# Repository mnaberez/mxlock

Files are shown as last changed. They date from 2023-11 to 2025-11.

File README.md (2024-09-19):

# MXLock

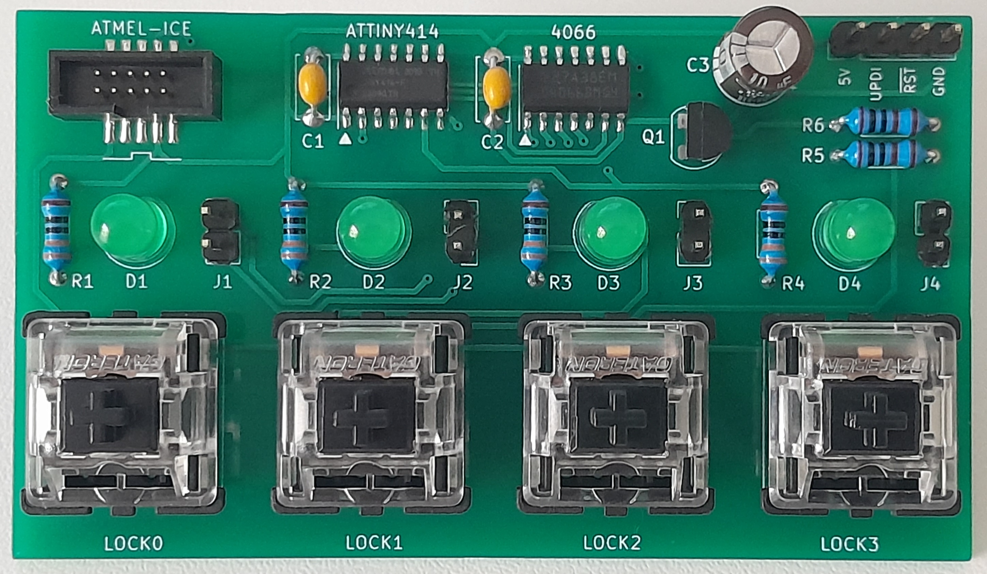
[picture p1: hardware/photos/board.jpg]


MXLock is a two-chip circuit that allows up to four mechanically locking keys (push-on, push-off) to be simulated using regular momentary key switches.

Many older computer keyboards have mechanically locking keys.  For example, the Commodore 128 has three locking keys: `SHIFT LOCK`, `CAPS LOCK`, and `40/80`.  The MXLock circuit can be included on the PCB of replacement keyboard projects, such as those using Cherry MX keys, so that the entire keyboard can be made from momentary key switches.

Features:

 - Simulates up to 4 locking keys using an [ATtiny214/414/814](https://web.archive.org/web/20231029180615if_/https://ww1.microchip.com/downloads/en/DeviceDoc/40001912A.pdf) and a [4066](https://web.archive.org/web/20231029180910if_/https://www.ti.com/lit/ds/symlink/cd4066b-mil.pdf)
 - Shows the on/off state of each key with LEDs
 - Remembers the lock states between power cycles (useful for mode keys like `40/80`)
 - Resets the computer by pulling `/RESET` low if the `LOCK0` key is held down
 - Puts the ATtiny to sleep between keypresses to save power

## Hardware

The [`hardware/`](./hardware/) directory in this repository contains the schematic and a PCB layout for the demonstration board pictured above.  It can be used to test the MXLock circuit.

The circuit is intended to be integrated directly onto the PCB of a keyboard.  Steve Gray's [C128SX keyboard](http://6502.org/users/sjgray/projects/mxkeyboards/) is an example of a keyboard using the circuit.

## Firmware

The firmware is written in AVR assembly language.  It can be assembled and flashed using open source software and inexpensive hardware.  See [`firmware/`](./firmware/) for the source code and instructions.

## Author

[Mike Naberezny](https://github.com/mnaberez)

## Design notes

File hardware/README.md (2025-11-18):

# Hardware 

The MXLock circuit consists of two main components: an ATtiny214/414/814 microcontroller and a 4066 quad analog switch.  The momentary key switches are connected directly to the microcontroller.  The 4066 is connected to the computer's keyboard matrix.

Up to four locking keys can be simulated, `LOCK0` through `LOCK3`: 

 - `LOCK0` can also reset the computer if held down.  If the circuit on the demo board is used, the computer must have an active-low reset input (`/RESET`) like on the 6502.
 - `LOCK1` and `LOCK2` have no special characteristics.
 - `LOCK3` has the limitation that its LED that can't be turned off programmatically unless its 4066 contact is also turned off.  LOCK3 may also prevent the ATtiny from entering shutdown mode (see note below).   If fewer than four keys are required, choose the others instead.

The design files are in KiCad format.  A [PDF schematic](./schematic.pdf) and [Gerber files](./gerbers.zip) are also available.  The PCB is only for demonstration and testing purposes; the MXLock circuit is intended to be integrated onto a keyboard.

See [`firmware/`](../firmware) for how to program the microcontroller.

## Power Consumption

The ATtiny is put into full shutdown mode (CPU and internal oscillator stopped) between keypressess.  At 5.0 VDC, with no key being pressed down and the 4066 contacts all in the open state, the [Joulescope JS220](https://www.joulescope.com) measures the demo board as drawing about 140 nA / 0.140 μA.

The demo board consumes about 8.5 mA total when one of the contacts is closed and its LED is lit.  This power draw is dominated by the LED.  The board consumes about 8.5 * 4 = 34 mA when all four contacts are closed and their LEDs are lit.  Different LEDs and current limiting resistors can be used to reduce power.  The LEDs can also be omitted for the lowest possible current draw.

`LOCK3` should be avoided if power consumption is a concern as it may prevent the ATtiny from shutting down.  Pressing `LOCK3` a few times may put the ATtiny into a state where it draws about 1.5 mA between keypresses even though all contacts and LEDs are off.  In this state, pressing `LOCK3` a few more times may return the current draw to normal (~ 140 nA).  The input pin for `LOCK3` is shared with the UPDI interface.  Presumably, activity on this pin puts the chip's internal UPDI circuitry into a state where it draws more power.

Notes:

- If a UPDI programmer is connected, the power consumption of the demo board increases.  Disconnect UPDI before measuring current.

- If different LEDs or current limiting resistors are used, each LED must draw no more than 12 mA or else damage to the ATtiny may occur.

## EEPROM Life

The internal EEPROM of the ATtiny is used to restore the state of the keys after power is lost.  The EEPROM is updated whenever a key changes state.  The firmware uses a wear-leveling algorithm to spread writes across the EEPROM locations for maximum life.

Although the ATtiny214 is supported, it should be avoided if longevity is a concern:

The ATtiny414 and ATtiny814 are preferred because they have twice the EEPROM space (128 bytes) as the ATtiny214 (64 bytes).  The ATtiny214 should withstand 6.4 million key
changes, the ATtiny414 and ATtiny814 should withstand twice that at 12.8 million.  

## Parts List

The demo board uses the following components:

| Part | Qty | Reference Designators |
|---|-----|---|
| [0.1uF 50V Capacitor](https://www.mouser.com/ProductDetail/594-K104M15X7RF53L2) | 2 | C1, C2 |
| [10uF 100V Capacitor](https://www.mouser.com/ProductDetail/661-E-101L100MF11D) | 1 | C3 |
| [T1-3/4 Green LED](https://www.mouser.com/ProductDetail/606-4304H5) | 4 | D1, D2, D3, D4 |
| [1x2 2.54mm Male Header](https://www.mouser.com/ProductDetail/649-1012937890201BLF) | 4 | J1, J2, J3, J4 |
| [10-pin 2x5 1.27mm Male Shrouded Header SMT](https://www.ebay.com/itm/171560426679) | 1 | J6 |
| [1x4 2.54mm Male Header](https://www.mouser.com/ProductDetail/649-1012937890401BLF) | 1 | J5 |
| [2N3904 Transistor](https://www.mouser.com/ProductDetail/512-2N3904BU) | 1 | Q1 |
| [330 ohm 1/4W Resistor](https://www.mouser.com/ProductDetail/603-MFR-25FTE52-330R) | 3 | R1, R2, R3, R4 |
| [1K 1/4W Resistor](https://www.mouser.com/ProductDetail/603-MFR-25FTF52-1K) | 1 | R5, R6 |
| [MX-Compatible Keyboard Switch](https://www.amazon.com/dp/B07K7J38SB) | 4 | SW1, SW2, SW3, SW4 |
| [ATtiny414-SSN](https://www.mouser.com/ProductDetail/579-ATTINY414-SSN) | 1 | U1 |
| [CD4066BM](https://www.mouser.com/ProductDetail/595-CD4066BM96) | 1 | U2 |

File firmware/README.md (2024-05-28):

# Firmware

The firmware is written in AVR assembly language.  It can be built for the ATtiny214, ATtiny414, and ATtiny814.

## Build

Building requires:

- ASAVR (part of the [ASxxxx](https://shop-pdp.net/ashtml/) cross-assemblers package)
- GNU [Make](https://www.gnu.org/software/make/)
- A Unix-like operating system (e.g. Linux, macOS)

Run `make` to produce Intel Hex files for the flash, fuses, and EEPROM:

    make MCU=t414

If `MCU=` is not given, the default target is `t414` (ATtiny414).  Valid targets are `MCU=t214`, `MCU=t414`, and `MCU=t814`.  It may be helpful to read the [`Makefile`](./Makefile) and the [GitHub workflow](../.github/workflows/main.yml).

## Flash

MXLock has a dedicated header for connecting to an [Atmel-ICE](https://www.microchip.com/en-us/development-tool/ATATMEL-ICE).  It also has pins on its 2.54mm header that can be used to connect to a different UPDI programmer.  In both cases, [AVRDUDE 7.2 or later](https://github.com/avrdudes/avrdude) is used.

### Atmel-ICE

Connect the Atmel-ICE to the dedicated header on the MXLock board.  Also connect a 5VDC power supply to the 5V and GND pins on the 2.54mm header.  Install the Atmel-ICE drivers and then run `make program`, specifying `MCU=` if needed.

### SerialUPDI

A SerialUPDI programmer can also be used.  One can be made from an FTDI [TTL-232R-5V](https://www.mouser.com/ProductDetail/895-TTL-232R-5V) cable and a 1KΩ resistor.  Make the following connections to the MXLock board:

- FTDI RX → UPDI
- FTDI TX → 1KΩ resistor → UPDI
- FTDI GND → GND

A 5VDC power supply must also be connected to the MXLock board.  The 5V pin on the FTDI cable may be used as the power supply.

Since macOS and most Linux distributions ship with built-in FTDI drivers, drivers are not normally required.  Run `make program` and use `ISPFLAGS=` to set the SerialUPDI options for AVRDUDE:

    make program MCU=t414 ISPFLAGS='-c serialupdi -P /dev/cu.usbserial-FTABCDEF'

The above command will flash an ATTiny414 using SerialUPDI on port `/dev/cu.usbserial-FTABCDEF`.

## References

- [ATtiny214/414/814 Datasheet](https://web.archive.org/web/20231029180615if_/https://ww1.microchip.com/downloads/en/DeviceDoc/40001912A.pdf)

- [AVR Instruction Set Manual](https://web.archive.org/web/20211122051203if_/http://ww1.microchip.com/downloads/en/devicedoc/atmel-0856-avr-instruction-set-manual.pdf)

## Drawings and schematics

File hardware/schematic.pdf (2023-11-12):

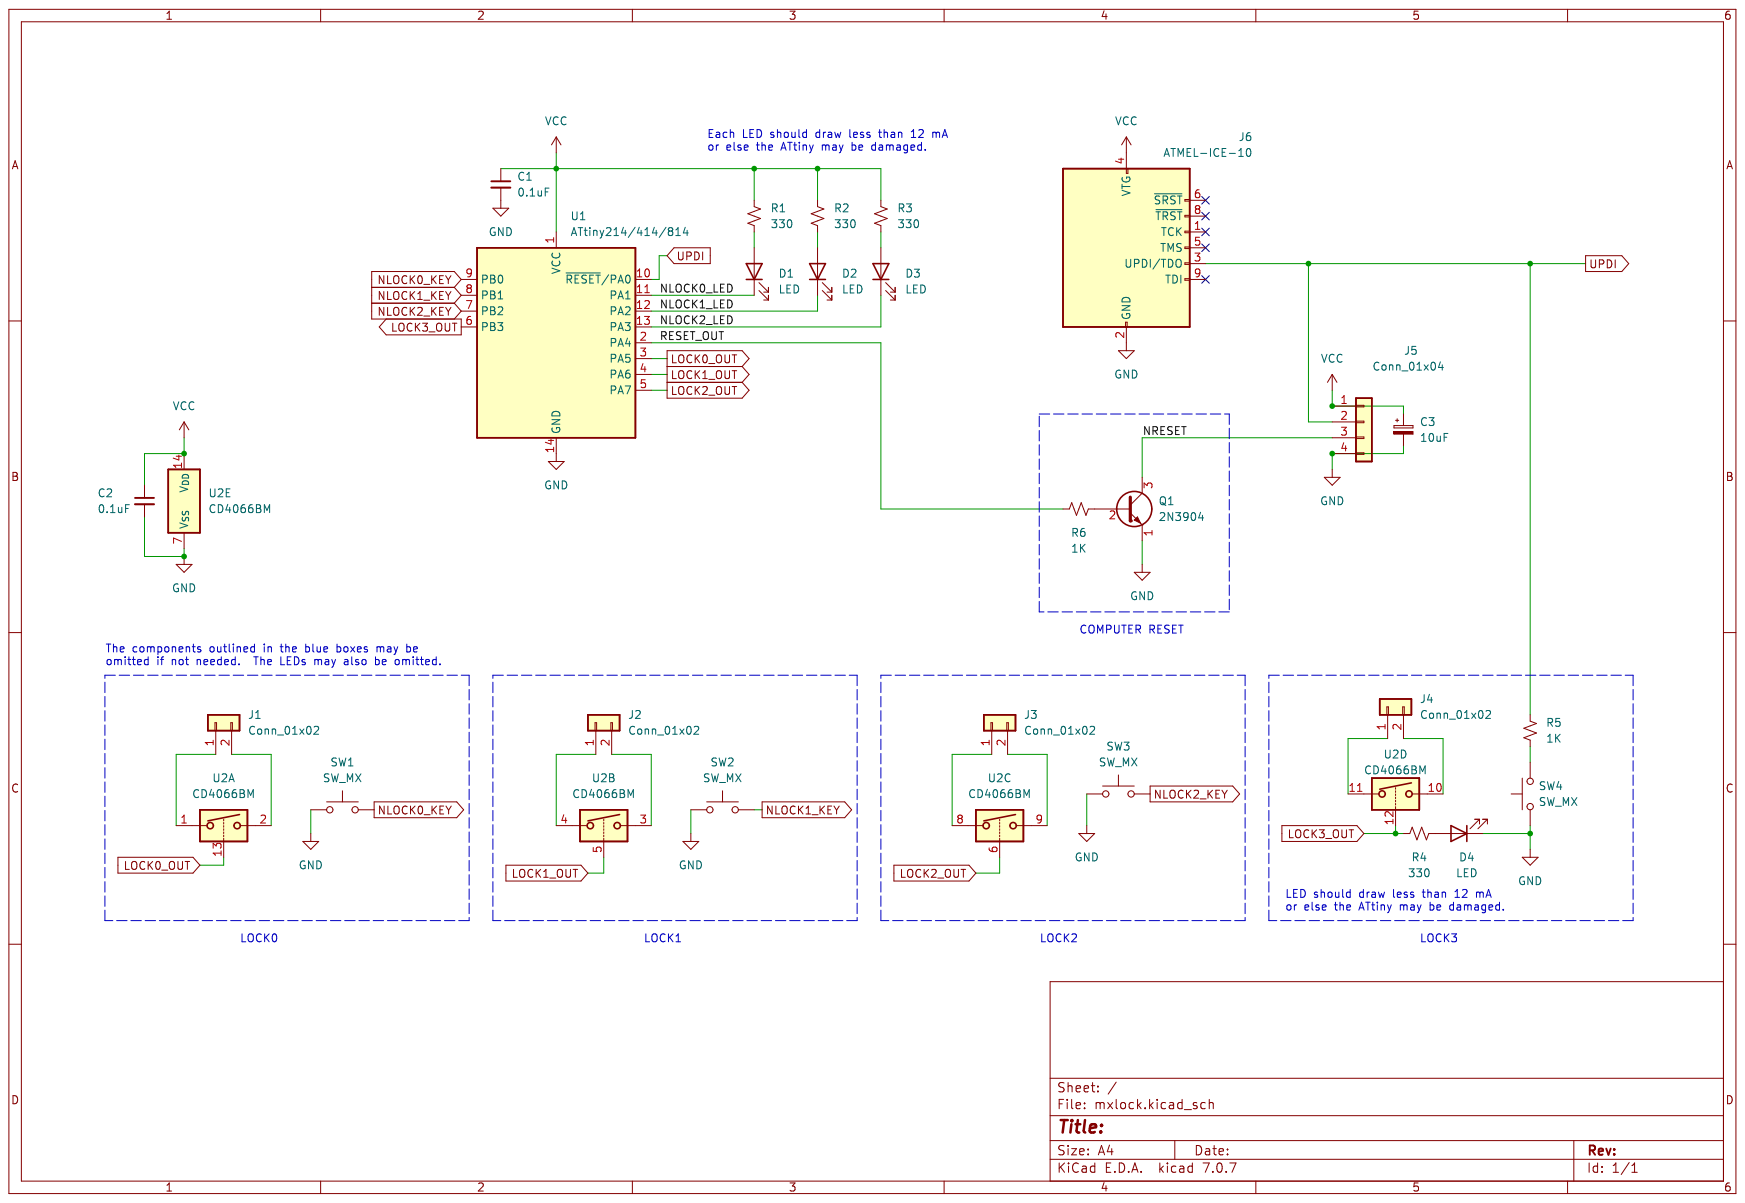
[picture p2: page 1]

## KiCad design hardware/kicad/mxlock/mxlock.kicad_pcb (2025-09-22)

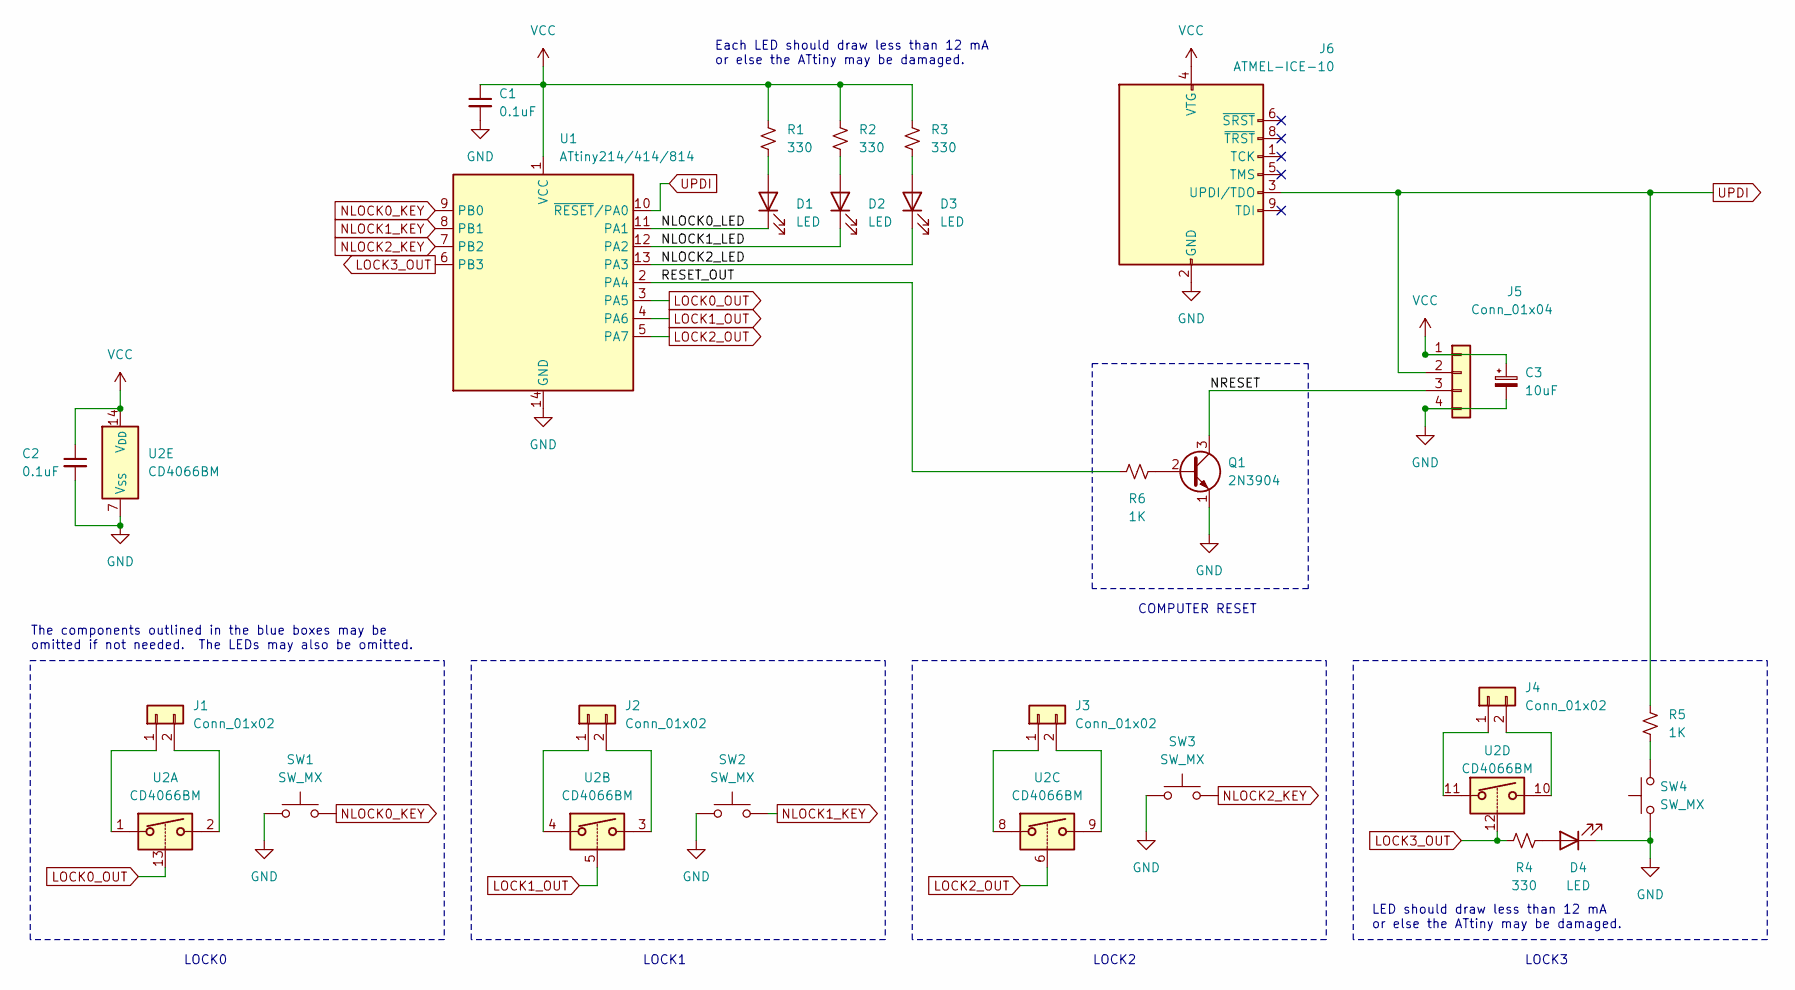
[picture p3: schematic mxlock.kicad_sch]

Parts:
C1, C2: 0.1uF; C_Disc_D5.0mm_W2.5mm_P5.00mm
C3: 10uF; CP_Radial_D6.3mm_P2.50mm
D1, D2, D3, D4: LED; LED_D5.0mm
J1, J2, J3, J4: Conn_01x02; PinHeader_1x02_P2.54mm_Vertical
J5: Conn_01x04; PinHeader_1x04_P2.54mm_Vertical
J6: ATMEL-ICE-10; PinHeader_2x05_P1.27mm_Shrouded_Vertical_SMD_Handsolder
Q1: 2N3904; TO-92_HandSolder
R1, R2, R3, R4: 330; R_Axial_DIN0204_L3.6mm_D1.6mm_P7.62mm_Horizontal
R5, R6: 1K; R_Axial_DIN0204_L3.6mm_D1.6mm_P7.62mm_Horizontal
SW1, SW2, SW3, SW4: SW_MX; SW_Cherry_MX_1.00u_PCB
U1: ATtiny214/414/814; SOIC-14_3.9x8.7mm_P1.27mm
U2: CD4066BM; SO-14_3.9x8.65mm_P1.27mm

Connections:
/NLOCK0_LED: D1.1 (K), U1.11 (PA1)
/NLOCK1_LED: D2.1 (K), U1.12 (PA2)
/NLOCK2_LED: D3.1 (K), U1.13 (PA3)
/NRESET: J5.3, Q1.3 (C)
/RESET_OUT: R6.1, U1.2 (PA4)
GND: C1.2, C2.2, C3.2, D4.1 (K), J5.4, J6.2 (GND), J6.10 (GND), Q1.1 (E), SW1.1, SW2.1, SW3.1, SW4.1, U1.14 (GND), U2.7 (V_{SS})
LOCK0_OUT: U1.3 (PA5), U2.13
LOCK1_OUT: U1.4 (PA6), U2.5
LOCK2_OUT: U1.5 (PA7), U2.6
LOCK3_OUT: R4.1, U1.6 (PB3), U2.12
NLOCK0_KEY: SW1.2, U1.9 (PB0)
NLOCK1_KEY: SW2.2, U1.8 (PB1)
NLOCK2_KEY: SW3.2, U1.7 (PB2)
unnamed: D1.2 (A), R1.2
unnamed: D2.2 (A), R2.2
unnamed: D3.2 (A), R3.2
unnamed: D4.2 (A), R4.2
unnamed: J1.1, U2.1
unnamed: J1.2, U2.2
unnamed: J2.1, U2.4
unnamed: J2.2, U2.3
unnamed: J3.1, U2.8
unnamed: J3.2, U2.9
unnamed: J4.1, U2.11
unnamed: J4.2, U2.10
unnamed: Q1.2 (B), R6.2
unnamed: R5.1, SW4.2
UPDI: J5.2, J6.3 (UPDI/TDO), R5.2, U1.10 (~RESET/PA0)
VCC: C1.1, C2.1, C3.1, J5.1, J6.4 (VTG), R1.1, R2.1, R3.1, U1.1 (VCC), U2.14 (V_{DD})

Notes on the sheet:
LOCK0
Each LED should draw less than 12 mA or else the ATtiny may be damaged.
LOCK3
LOCK1
COMPUTER RESET
The components outlined in the blue boxes may be omitted if not needed. The LEDs may also be omitted.
LED should draw less than 12 mA or else the ATtiny may be damaged.
LOCK2

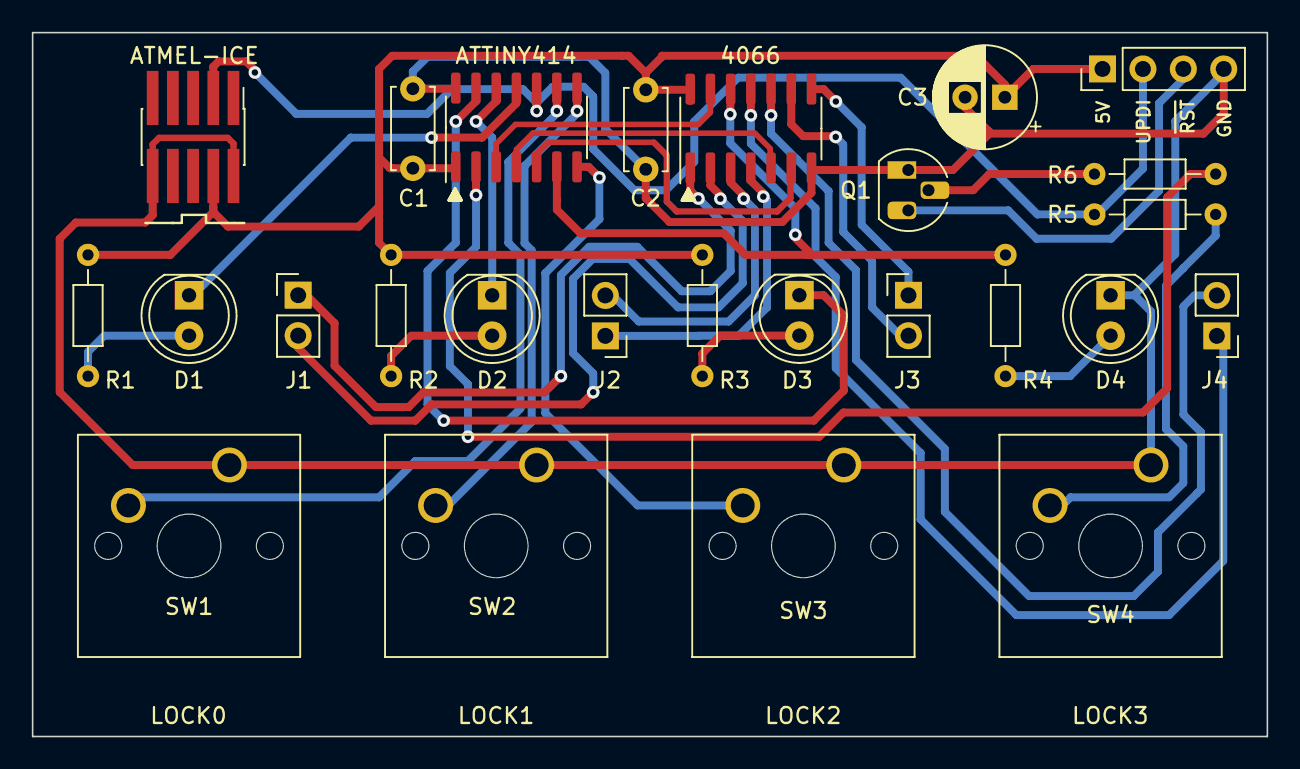
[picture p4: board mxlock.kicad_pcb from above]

Board: 2 copper layers, 77.6 x 44.2 mm, 26 parts (0 on the bottom side), 29 nets.

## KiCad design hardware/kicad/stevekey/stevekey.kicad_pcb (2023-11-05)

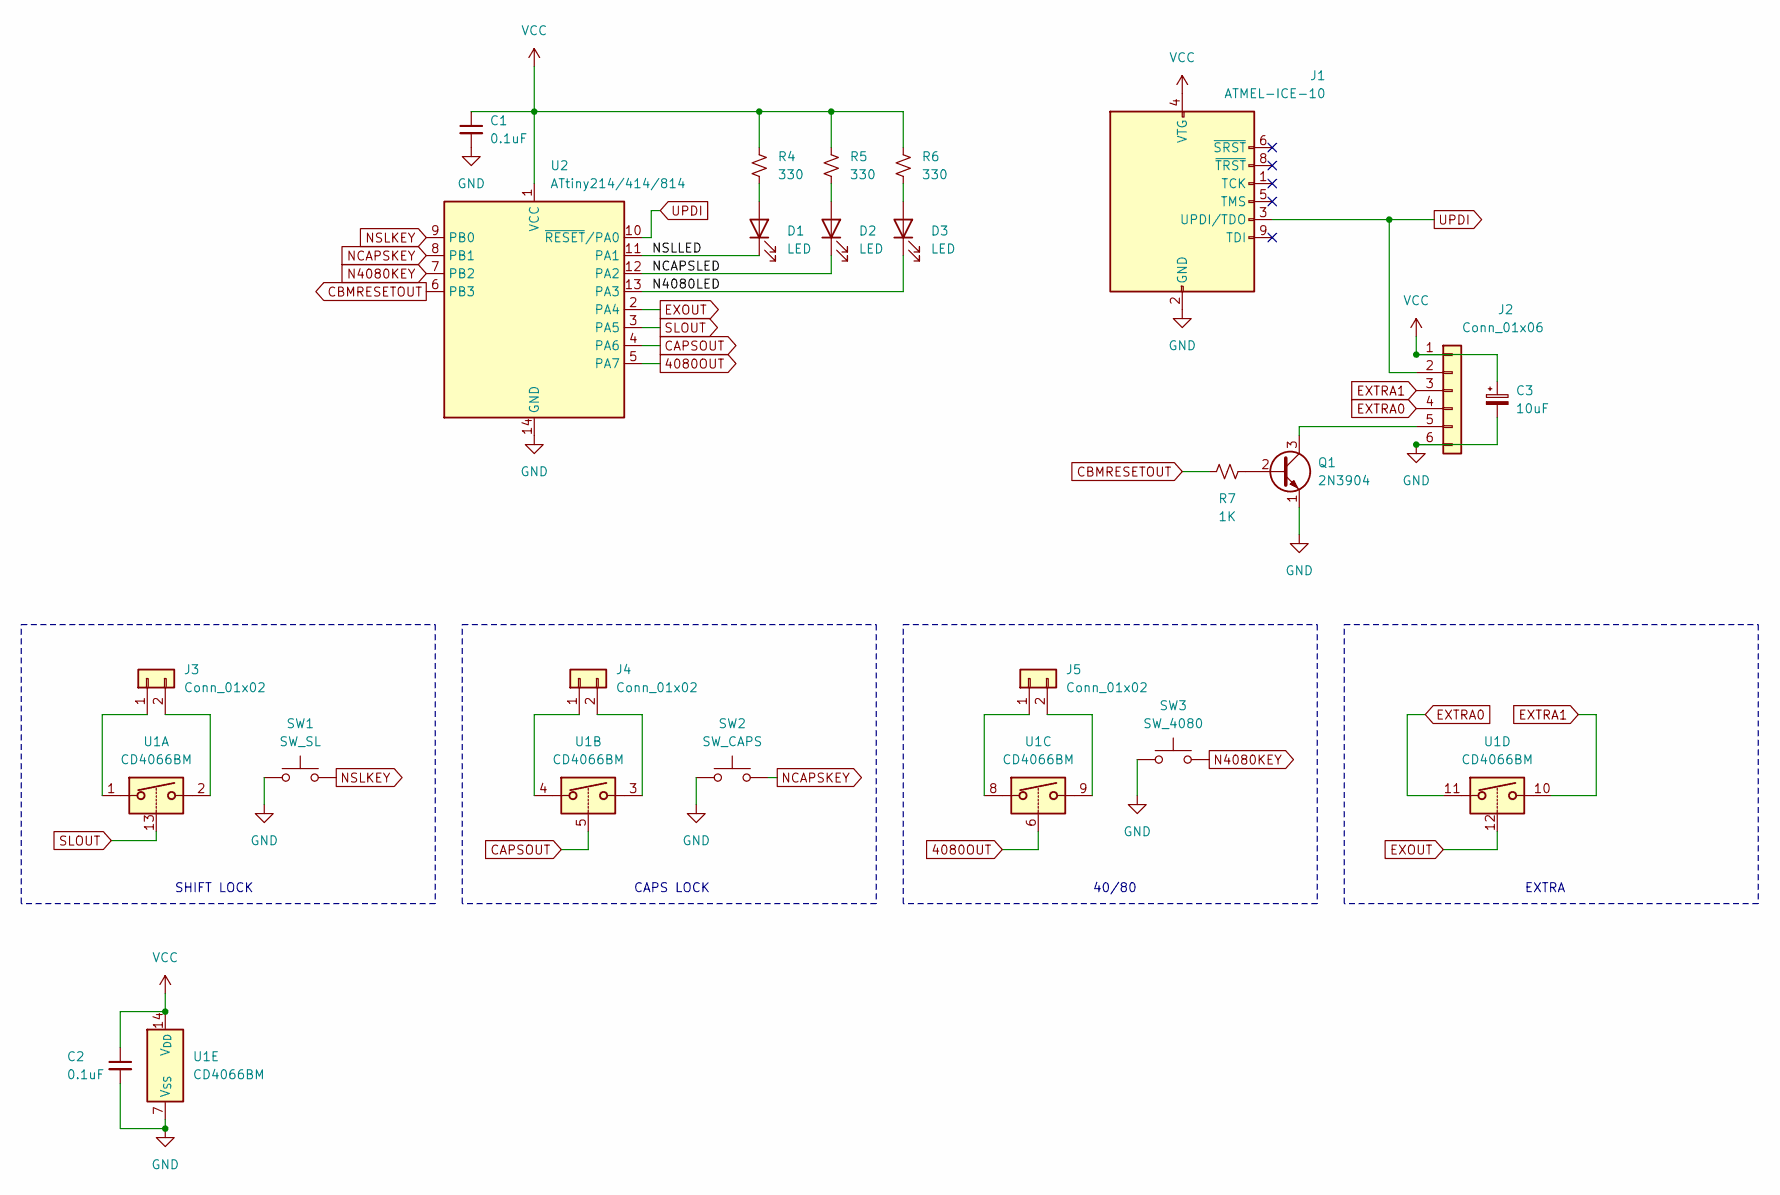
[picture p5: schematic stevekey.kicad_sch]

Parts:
C1, C2: 0.1uF; C_Disc_D5.0mm_W2.5mm_P5.00mm
C3: 10uF; CP_Radial_D6.3mm_P2.50mm
D1, D2, D3: LED; LED_D5.0mm
J1: ATMEL-ICE-10; PinHeader_2x05_P1.27mm_Shrouded_Vertical_SMD_Handsolder
J2: Conn_01x06; PinHeader_1x06_P2.54mm_Vertical
J3, J4, J5: Conn_01x02; PinHeader_1x02_P2.54mm_Vertical
Q1: 2N3904; TO-92_Inline
R4, R5, R6: 330; R_Axial_DIN0204_L3.6mm_D1.6mm_P7.62mm_Horizontal
R7: 1K; R_Axial_DIN0204_L3.6mm_D1.6mm_P7.62mm_Horizontal
SW1: SW_SL; SW_Cherry_MX_1.00u_PCB
SW2: SW_CAPS; SW_Cherry_MX_1.00u_PCB
SW3: SW_4080; SW_Cherry_MX_1.00u_PCB
U1: CD4066BM; SO-14_3.9x8.65mm_P1.27mm
U2: ATtiny214/414/814; SOIC-14_3.9x8.7mm_P1.27mm

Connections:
4080OUT: U1.6, U2.5 (PA7)
/N4080LED: D3.1 (K), U2.13 (PA3)
/NCAPSLED: D2.1 (K), U2.12 (PA2)
/NSLLED: D1.1 (K), U2.11 (PA1)
CAPSOUT: U1.5, U2.4 (PA6)
CBMRESETOUT: R7.1, U2.6 (PB3)
EXOUT: U1.12, U2.2 (PA4)
EXTRA0: J2.4, U1.11
EXTRA1: J2.3, U1.10
GND: C1.2, C2.2, C3.2, J1.2 (GND), J1.10 (GND), J2.6, Q1.1 (E), SW1.1, SW2.1, SW3.1, U1.7 (V_{SS}), U2.14 (GND)
N4080KEY: SW3.2, U2.7 (PB2)
NCAPSKEY: SW2.2, U2.8 (PB1)
NSLKEY: SW1.2, U2.9 (PB0)
unnamed: D1.2 (A), R4.2
unnamed: D2.2 (A), R5.2
unnamed: D3.2 (A), R6.2
unnamed: J2.5, Q1.3 (C)
unnamed: J3.1, U1.1
unnamed: J3.2, U1.2
unnamed: J4.1, U1.4
unnamed: J4.2, U1.3
unnamed: J5.1, U1.8
unnamed: J5.2, U1.9
unnamed: Q1.2 (B), R7.2
SLOUT: U1.13, U2.3 (PA5)
UPDI: J1.3 (UPDI/TDO), J2.2, U2.10 (~RESET/PA0)
VCC: C1.1, C2.1, C3.1, J1.4 (VTG), J2.1, R4.1, R5.1, R6.1, U1.14 (V_{DD}), U2.1 (VCC)

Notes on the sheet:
SHIFT LOCK
EXTRA
CAPS LOCK
40/80

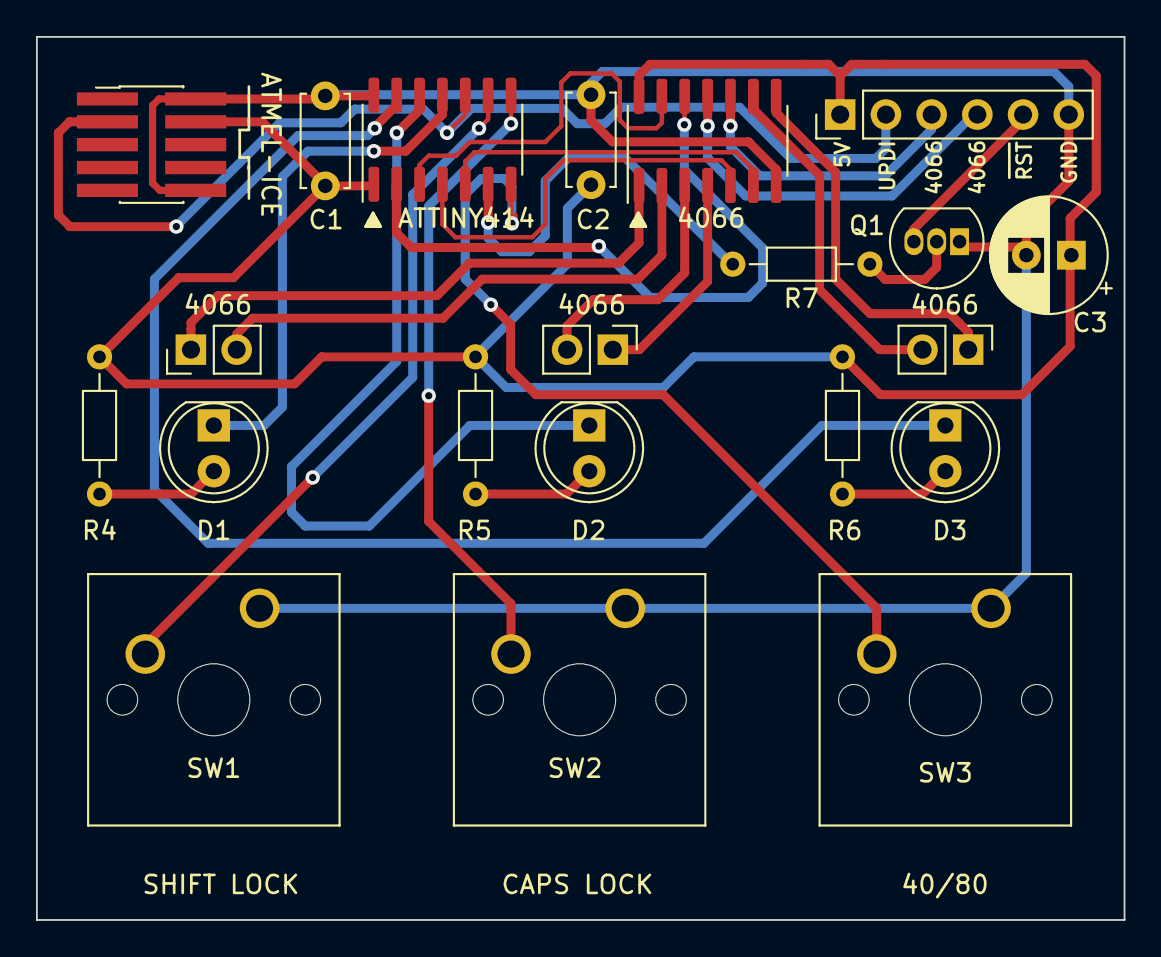
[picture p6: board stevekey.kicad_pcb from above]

Board: 2 copper layers, 60.4 x 49.1 mm, 21 parts (0 on the bottom side), 27 nets.

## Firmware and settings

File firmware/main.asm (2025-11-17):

;ATtiny214/ATtiny414/ATtiny814
;1  VCC
;2  PA4 out RESET_OUT (0=/RESET=open, 1=/RESET=low)
;3  PA5 out LOCK0_OUT to 4066 (0=off, 1=on)
;4  PA6 out LOCK1_OUT to 4066 (0=off, 1=on)
;5  PA7 out LOCK2_OUT to 4066 (0=off, 1=on)
;6  PB3 out LOCK3_OUT to 4066 and LED (0=off, 1=on)
;7  PB2 in /LOCK2_KEY (0=down, 1=up)
;8  PB1 in /LOCK1_KEY (0=down, 1=up)
;9  PB0 in /LOCK0_KEY (0=down, 1=up)
;10 UPDI/PA0 in /LOCK3_KEY (0=down, 1=up)
;11 PA1 out /LOCK0_LED (0=on, 1=off)
;12 PA2 out /LOCK1_LED (0=on, 1=off)
;13 PA3 out /LOCK2_LED (0=on, 1=off)
;14 GND

    ;Definitions file will be included first by the Makefile.

    .area code (abs)
    .list (me)
    .32bit

;RAM
current_keys     = SRAM_START+0 ;Current state of keys
previous_keys    = SRAM_START+1 ;State of keys last time around the main loop
lock0_down_ticks = SRAM_START+2 ;Number of ticks LOCK0 has been held down

;Constants
TICK_MS         = 20    ;Milliseconds in one tick
RESET_MS        = 50    ;Milliseconds to hold /RESET low to reset
LOCK0_DOWN_MS   = 1500  ;Milliseconds of LOCK0 held down to cause reset

;Constants for bit positions used with GPIO functions
LOCK3 = 3
LOCK2 = 2
LOCK1 = 1
LOCK0 = 0

    .org PROGMEM_START/2  ;/2 because PROGMEM_START constant is byte-addressed
                          ;but ASAVR treats program space as word-addressed.

    ;Vectors
    rjmp reset            ;00 RESET
    rjmp isr_fatal        ;01 CRCSCAN_NMI
    rjmp isr_fatal        ;02 BOD_VLM
    rjmp isr_pin_change   ;03 PORTA_PORT
    rjmp isr_pin_change   ;04 PORTB_PORT
    rjmp isr_fatal        ;05 Undefined
    rjmp isr_fatal        ;06 RTC_CNT
    rjmp isr_fatal        ;07 RTC_PIT
    rjmp isr_fatal        ;08 TCA0_LUNF / TCA0_OVF
    rjmp isr_fatal        ;09 TCA0_HUNF
    rjmp isr_fatal        ;0a TCA0_LCMP0 / TCA0_CMP0
    rjmp isr_fatal        ;0b TCA0_LCMP1 / TCA0_CMP1
    rjmp isr_fatal        ;0c TCA0_CMP2 / TCA0_LCMP2
    rjmp isr_fatal        ;0d TCB0_INT
    rjmp isr_fatal        ;0e TCD0_OVF
    rjmp isr_fatal        ;0f TCD0_TRIG
    rjmp isr_fatal        ;10 AC0_AC
    rjmp isr_fatal        ;11 ACD0_RESRDY
    rjmp isr_fatal        ;12 ACD0_WCOMP
    rjmp isr_fatal        ;13 TWI0_TWIS
    rjmp isr_fatal        ;14 TWI0_TWIM
    rjmp isr_fatal        ;15 SPI0_INT
    rjmp isr_fatal        ;16 USART0_RXC
    rjmp isr_fatal        ;17 USART0_DRE
    rjmp isr_fatal        ;18 USART0_TXC
    rjmp isr_fatal        ;19 NVMCTRL_EE

    ;Code starts at first location after vectors
    .assume . - ((PROGMEM_START/2) + INT_VECTORS_SIZE)

;Unexpected interrupt
;
isr_fatal:
    jmp fatal

;Pin change interrupt
;
;The pin change interrupts are enabled in order to wake
;from sleep but are not used for anything else.  When a
;pin change interrupt occurs, its flags must be cleared.
;
isr_pin_change:
    push r16
    ldi r16, 0xff                       ;Clear every flag
    sts PORTA_INTFLAGS, r16             ;  on PORTA
    sts PORTB_INTFLAGS, r16             ;  on PORTB
    pop r16
    reti

;Reset
;
;Perform all startup activities, then start running the main loop.
;
reset:
    ;Set main clock to 16 MHz to get through init quickly
    ;in case the computer checks for a key at boot.
    ldi r16, CPU_CCP_IOREG_gc
    clr r17                             ;No prescaler = 16 MHz
    out CPU_CCP, r16                    ;Unlock Protected I/O Registers
    sts CLKCTRL_MCLKCTRLB, r17          ;Disable main clock prescaler

    ;Initialize stack pointer
    ldi r16, <INTERNAL_SRAM_END
    out CPU_SPL, r16
    ldi r16, >INTERNAL_SRAM_END
    out CPU_SPH, r16

    ;Initialize GPIO and restore 4066 contacts to last saved state
    rcall gpio_init
    rcall eeprom_read_contacts  
    rcall gpio_write_contacts   

    ;Now that the 4066 is set up, drop down to 1 MHz.  The clock
    ;will run at 1 MHz from now on to save a little power.
    ldi r16, CPU_CCP_IOREG_gc
    ldi r17, 0x03<<1 | CLKCTRL_PEN_bm   ;Prescaler for 1 MHz
    out CPU_CCP, r16                    ;Unlock Protected I/O Registers
    sts CLKCTRL_MCLKCTRLB, r17          ;Set main clock prescaler

    ;Initialize variables to defaults
    clr r16
    sts current_keys, r16
    sts previous_keys, r16
    sts lock0_down_ticks, r16

    ;Initialize remaining peripherals and enable interrupts
    rcall sleep_init
    sei

    ;Fall through

main_loop:
    rcall task_keys             ;Read key state, remember previous state
    rcall task_contacts         ;Flip 4066 contact for any key just pressed
    rcall task_reset            ;Reset computer if LOCK0 is held down
    rcall task_eeprom           ;Store 4066 contacts in EEPROM
    rcall task_leds             ;Update LEDs from 4066 contacts
    rcall task_sleep            ;Go to sleep until a key changes

    rjmp main_loop              ;Loop forever

;TASKS ======================================================================

;Read the current state of the keys and remember the previous state.
;This task blocks for 1 tick to debounce.
;
task_keys:
    lds r16, current_keys       
    sts previous_keys, r16      ;Save keys from last time called

    rcall read_debounced_keys   ;Read keys (blocks for 1 tick)
    sts current_keys, r16       ;Save current keys

    ret

;Check each key and toggle its 4066 contact if it was just pressed down.
;
task_contacts:
    ldi r18, 1<<LOCK3           ;First key to check (highest bit position)

1$: lds r16, current_keys
    and r16, r18                ;Leave only key of interest from current
    breq 2$                     ;Branch if key is not down

    lds r17, previous_keys
    and r17, r18                ;Leave only key of interest from previous
    eor r17, r16                ;Compare with current state of key
    breq 2$                     ;Branch if key has not changed

    ;Key has changed and is down
    rcall gpio_read_contacts
    eor r16, r18                ;Toggle the 4066 contact
    rcall gpio_write_contacts

2$: lsr r18                     ;Rotate right to next key
    brne 1$                     ;Loop until all keys are checked

    ret

;Check for reset request and reset the computer if needed
;If LOCK0 is held down long enough, reset the computer, restore the
;previous LOCK0 state, and block until LOCK0 is released.
;
task_reset:
    lds r16, current_keys
    lds r17, lock0_down_ticks
    sbrs r16, LOCK0             ;Skip next if LOCK0 is down
    clr r17
    cpi r17, #0xff              ;Cap tick counter (do not wrap to 0)
    breq 1$
    inc r17
1$: sts lock0_down_ticks, r17

    cpi r17, LOCK0_DOWN_MS/TICK_MS ;Held down long enough to reset?
    brlo 3$

    ;LOCK0 held down long enough; it's time to reset the computer

    ;Reset count for next time
    clr r16
    sts lock0_down_ticks, r16

    ;Restore LOCK0 to its state before being pressed down
    rcall gpio_read_contacts
    ldi r17, 1<<LOCK0
    eor r16, r17
    rcall gpio_write_contacts
    rcall gpio_write_leds

    ;Pulse /RESET low
    rcall gpio_reset_on
    ldi r16, RESET_MS
    rcall wait_n_ms
    rcall gpio_reset_off

    ;Wait for LOCK0 to be released (prevents multiple resets)
2$: rcall read_debounced_keys
    sts current_keys, r16
    wdr
    sbrc r16, LOCK0
    rjmp 2$

3$: ret

;Update 4066 contact state in EEPROM if needed
;
task_eeprom:
    lds r16, current_keys
    or r16, r16
    brne 1$                     ;Do nothing if any key is down

    rcall eeprom_read_contacts
    mov r17, r16
    rcall gpio_read_contacts
    cp r16, r17
    breq 1$                     ;Do nothing if no change

    ;Contacts do not match the EEPROM, time to write to the EEPROM

    mov r17, r16                ;Save contacts in R17

    clr r16                     ;Turn off LEDs so that if power is lost,
    rcall gpio_write_leds       ;  they take no residual power from EEPROM

    mov r16, r17                ;Recall contacts 
    rcall eeprom_write_contacts 

1$: ret

;Update the LEDs from the 4066 contacts
;
;This task should be called before the sleep task to ensure 
;the LEDs reflect the 4066 contacts because other tasks may 
;temporarily change the LEDs.
;
task_leds:
    rcall gpio_read_contacts    
    rjmp gpio_write_leds        

;Go to sleep until a key changes
;
;This task should always be the last one called.  It puts the
;MCU to sleep until a key is pressed in order to save power.
;
task_sleep:
    lds r16, current_keys
    or r16, r16
    brne 1$                     ;Do nothing if any key is down

    sleep                       ;Returns when MCU wakes back up

1$: ret

;UTILITIES ==================================================================

;Read the keys with gpio_read_keys and debounce for one tick
;
read_debounced_keys:
    push r18
    push r17

1$: ldi r18, TICK_MS          ;Debounce time
2$: rcall wait_1_ms
    rcall gpio_read_keys      ;Returns keys in R16
    cp r16, r17               ;Same as last keys?
    mov r17, r16              
    brne 1$                   ;  No: start all over

    dec r18                    
    brne 2$                   ;Loop for debounce time

    pop r17
    pop r18
    ret

;Busy wait for N milliseconds in R16
;
wait_n_ms:
    rcall wait_1_ms
    dec r16
    brne wait_n_ms
    ret

;Busy wait for 1 millisecond
;Assumes 1 MHz clock
;
wait_1_ms:
    push r16
    push r17

    ldi r16, 0x02
1$: ldi r17, 0xa6
2$: dec r17
    brne 2$
    dec r16
    brne 1$

    pop r17
    pop r16
    ret

;GPIO =======================================================================

;
;The GPIO routines abstract the I/O pins such that the bit
;positions in the constants LOCK0-LOCK3 are used for all the 
;routines (the key inputs, LED outputs, and 4066 contacts).
;
;The bit values use positive logic:
;
; - A bit of "0" means key up / LED off / 4066 contact open
; - A bit of "1" means key down / LED on / 4066 contact closed
;

;Read all the key switch inputs and return them in R16
;0=key up, 1=key down
;
gpio_read_keys:
    push r17

    clr r16

    lds r17, PORTA_IN
    sbrs r17, 0             ;UPDI/PA0 clear
    ori r16, 1<<LOCK3       ;  sets LOCK3 bit

    lds r17, PORTB_IN
    sbrs r17, 2             ;PB2 clear
    ori r16, 1<<LOCK2       ;  sets LOCK2 bit
    sbrs r17, 1             ;PB1 clear
    ori r16, 1<<LOCK1       ;  sets LOCK1 bit
    sbrs r17, 0             ;PB0 clear
    ori r16, 1<<LOCK0       ;  sets LOCK0 bit

    pop r17
    ret

;Write all the 4066 contacts from the value in R16
;0=contact open, 1=contact closed
;
gpio_write_contacts:
    push r17

    lds r17, PORTA_OUT
    andi r17, 0xff ^ (1<<7 | 1<<6 | 1<<5)
    sbrc r16, LOCK0    
    ori r17, 1<<5           ;LOCK0 bit set sets PA5
    sbrc r16, LOCK1     
    ori r17, 1<<6           ;LOCK1 bit set sets PA6
    sbrc r16, LOCK2         
    ori r17, 1<<7           ;LOCK2 bit set sets PA7
    sts PORTA_OUT, r17

    lds r17, PORTB_OUT
    andi r17, 0xff ^ (1<<3)
    sbrc r16, LOCK3
    ori r17, 1<<3           ;LOCK3 bit set sets PB3
    sts PORTB_OUT, r17

    pop r17
    ret

;Read the state of all the 4066 contacts into R16
;0=contact open, 1=contact closed
;
gpio_read_contacts:
    push r17

    clr r16

    lds r17, PORTA_OUT
    sbrc r17, 5                 
    ori r16, 1<<LOCK0       ;PA5 set sets LOCK0 bit
    sbrc r17, 6                 
    ori r16, 1<<LOCK1       ;PA6 set sets LOCK1 bit
    sbrc r17, 7                 
    ori r16, 1<<LOCK2       ;PA7 set sets LOCK2 bit

    lds r17, PORTB_OUT
    sbrc r17, 3
    ori r16, 1<<LOCK3       ;PB3 set sets LOCK3 bit

    pop r17
    ret

;Write all the LED outputs from the value in R16
;0=LED off, 1=LED on
;
gpio_write_leds:
    push r17

    lds r17, PORTA_OUT
    andi r17, 0xff ^ (1<<3 | 1<<2 | 1<<1)    
    sbrs r16, LOCK0    
    ori r17, 1<<1           ;LOCK0 bit clear sets PA1
    sbrs r16, LOCK1     
    ori r17, 1<<2           ;LOCK1 bit clear sets PA2
    sbrs r16, LOCK2         
    ori r17, 1<<3           ;LOCK2 bit clear sets PA3
    sts PORTA_OUT, r17

    ;Note: The LED for LOCK3 is different.  It's ignored
    ;here because it's on whenever its 4066 contact is on.

    pop r17
    ret

;Read the state of all the LED outputs into R16
;0=LED off, 1=LED on
;
gpio_read_leds:
    push r17

    clr r16

    lds r17, PORTA_OUT
    sbrs r17, 1                 
    ori r16, 1<<LOCK0       ;PA1 clear sets LOCK0 bit
    sbrs r17, 2
    ori r16, 1<<LOCK1       ;PA2 clear sets LOCK1 bit
    sbrs r17, 3
    ori r16, 1<<LOCK2       ;PA3 clear sets LOCK2 bit

    ;Note: The LED for LOCK3 is different.  It's on whenever
    ;its 4066 contact is on, so the 4066 contact is tested here.

    lds r17, PORTB_OUT
    sbrc r17, 3
    ori r16, 1<<LOCK3       ;PB3 set sets LOCK3 bit

    pop r17
    ret

;Pull the /RESET pin to GND, resetting the computer
;
gpio_reset_on:
    ldi r16, 1<<4           ;PA4
    sts PORTA_OUTSET, r16   ;set PA4=1 which pulls /RESET low
    ret

;Open the /RESET pin, allowing the computer to run
;
gpio_reset_off:
    ldi r16, 1<<4           ;PA4
    sts PORTA_OUTCLR, r16   ;set PA4=0 which makes /RESET open
    ret

;Set initial GPIO directions and states
;
; - Key pins as inputs
; - LED pins as outputs; LEDs not lit
; - 4066 pins as outputs; contacts open
; - RESET_OUT pin as output; /RESET=open
;
gpio_init:
    ;Key Inputs
    ldi r16, 1<<2 | 1<<1 | 1<<0     ;PB2, PB1, PB0
    sts PORTB_DIRCLR, r16           ;Set pins as input

    ;Enable pull-ups and pin-change interrupts
    ldi r16, PORT_PULLUPEN_bm | PORT_ISC_BOTHEDGES_gc
    sts PORTB_PIN2CTRL, r16         ; on PB2
    sts PORTB_PIN1CTRL, r16         ; on PB1
    sts PORTB_PIN0CTRL, r16         ; on PB0

    ;UPDI/PA0 Key Input
    ldi r16, 1<<0                   ;UPDI/PA0
    sts PORTA_DIRCLR, r16           ;Set UPDI pin also as a GPIO input
    ldi r16, PORT_ISC_BOTHEDGES_gc
    sts PORTA_PIN0CTRL, r16         ;Enable pin change interrupt on PA0

    ;Note: The UPDI/PA0 pin is configured for UPDI in the fuses.  In UPDI
    ;mode, the pin can still be used as an input.  The MCU can still be
    ;programmed with UPDI as long as the key is not pressed down.  No pull-up
    ;is configured because UPDI mode has its own special pull-up.

    ;4066 Outputs
    ldi r16, 1<<7 | 1<<6 | 1<<5     ;PA7, PA6, PA5
    sts PORTA_OUTCLR, r16           ;Set 4066s initially off (0=off)
    sts PORTA_DIRSET, r16           ;Set pins as outputs
    ldi r16, 1<<3                   ;PB3
    sts PORTB_OUTCLR, r16           ;Set 4066s initially off (0=off)
    sts PORTB_DIRSET, r16           ;Set pins as outputs

    ;LED Outputs
    ldi r16, 1<<3 | 1<<2 | 1<<1     ;PA3, PA2, PA1
    sts PORTA_OUTSET, r16           ;Sets LEDs initially off (1=off)
    sts PORTA_DIRSET, r16           ;Set pins as outputs

    ;RESET_OUT Output
    ldi r16, 1<<4                   ;PA4
    sts PORTA_OUTCLR, r16           ;Set RESET_OUT initially off (0=off)
    sts PORTA_DIRSET, r16           ;Set PA4 as output
    ret

;SLEEP ======================================================================

sleep_init:
    ldi r16, SLPCTRL_SEN_bm | SLPCTRL_SMODE_PDOWN_gc
    sts SLPCTRL_CTRLA, r16
    ret

;EEPROM =====================================================================

;
;The EEPROM is used to store the state of the 4066 contacts, which is only
;1 byte.  However, there are 64 bytes available in the EEPROM on the 
;ATtiny214 and 128 bytes on the ATTiny414/814.  Since each EEPROM location
;can only be erased about 100K times, the entire area is used to store the 
;1 byte using this wear-leveling algorithm:
;
; - To write the 4066 contacts byte, the lowest location in the EEPROM that
;   is erased (0xFF) will receive the byte using the write-only (no erase)
;   command.  If no location contains 0xFF, the entire EEPROM will be erased
;   back to 0xFF and the first location will receive the byte.
;
; - To read the 4066 contacts byte from the EEPROM, the byte in the highest
;   location that does not contain 0xFF will be returned.
;
;The above algorithm will hopefully allow the 4066 contacts to change
;64 * 100K (6.4 million) times on the ATtiny214 or 128 * 100K (12.8 million)
;times on the ATtiny414/814 before the EEPROM wears out.
;

;Read 4066 contact state from the EEPROM into R16
;Destroys Y
;
;Find the highest location in the EEPROM that is
;not erased (0xFF) and return its value.  If the
;entire EEPROM is empty, return 0 (all contacts off).
;
eeprom_read_contacts:
    ldi YL, <(EEPROM_END+1)
    ldi YH, >(EEPROM_END+1)
1$: ld r16, -Y                          ;Load byte currently in EEPROM
    cpi r16, #0xff                      ;Erased (0xFF)?
    brne 2$                             ;  No: branch to return this byte
    cpi YL, #<EEPROM_START
    brne 1$
    cpi YH, #>EEPROM_START
    brne 1$
    clr r16                             ;EEPROM is empty; return 0 (all off)
2$: ret

;Store R16 as the 4066 contact state in the EEPROM
;Destroys R16, R17, Y
;
;Find the lowest location in the EEPROM that is erased (0xFF) and
;write the value there.  If there is no unerased location, erase
;the entire EEPROM and write the value in the first location.
;
eeprom_write_contacts:
    rcall eeprom_wait_ready

    ldi YL, <EEPROM_START
    ldi YH, >EEPROM_START

1$: ld r17, Y+                          ;Load byte currently in EEPROM
    cpi r17, #0xff                      ;Erased (0xFF)?
    breq 2$                             ;  Yes: branch to write byte here

    cpi YL, <(EEPROM_END+1)
    brne 1$
    cpi YH, >(EEPROM_END+1)
    brne 1$

    ;No unerased byte; erase EEPROM and reset pointer
    push r16                            ;Save 4066 contacts
    ldi r16, NVMCTRL_CMD_EEERASE_gc     ;Erase EEPROM command
    rcall eeprom_send_cmd
    pop r16                             ;Recall 4066 contacts
    ldi YL, <(EEPROM_START+1)
    ldi YH, <(EEPROM_START+1)

2$: st -Y, r16                          ;Store 4066 contacts in buffer                 
    ldi r16, NVMCTRL_CMD_PAGEWRITE_gc   ;Write-only command

    ;Fall through

;Send the NVMCTRL command in R16
;Destroys R17
;
eeprom_send_cmd:
    ldi r17, CPU_CCP_SPM_gc
    out CPU_CCP, r17                    ;Unlock NVMCTRL_CTRLA
    sts NVMCTRL_CTRLA, r16              ;Perform EEPROM command in R16

    ;Fall through

;Block until the EEPROM is ready
;Destroys R17
;
eeprom_wait_ready:
    lds r17, NVMCTRL_STATUS
    sbrc r17, NVMCTRL_EEBUSY_bp         ;Skip next if EEPROM is ready
    rjmp eeprom_wait_ready
    ret

;END OF CODE ================================================================

    ;Fill all unused program words with a nop sled that ends with
    ;a software reset in case the program counter somehow gets here.
    .nval filler_start,.
    .rept ((PROGMEM_END/2) - filler_start - fatal_size)
    nop
    .endm

;Fatal error causes software reset
fatal:
    cli                       ;Disable interrupts
    ldi r16, CPU_CCP_IOREG_gc
    ldi r17, RSTCTRL_SWRE_bm
    out CPU_CCP, r16          ;Unlock Protected I/O Registers
    sts RSTCTRL_SWRR, r17     ;Software Reset

fatal_size = . - 1 - fatal

;Entire flash memory should be filled
    .assume . - (PROGMEM_SIZE/2)

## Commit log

2023-08-26 Remove ROM test since it's done automatically on reset
    [main.asm]
2023-10-02 Start schematic
    [stevekey.kicad_pcb, stevekey.kicad_sch]
2023-10-08 Start board layout
    [stevekey.kicad_pcb, stevekey.kicad_sch]
2023-10-11 Initial routing is complete
    [stevekey.kicad_pcb, stevekey.kicad_sch]
2023-10-11 Add transistor to pull /RES down
    [stevekey.kicad_pcb, stevekey.kicad_sch]
2023-10-11 Bring the extra 4066 pins out to the header
    [stevekey.kicad_pcb, stevekey.kicad_sch]
2023-10-11 Remove old KiCad backup files
2023-10-11 Fix values of C1 and C2
    [stevekey.kicad_sch]
2023-10-11 Add capacitor on input power
    [stevekey.kicad_pcb, stevekey.kicad_sch]
2023-10-11 Add directory for Gerber outputs
2023-10-11 Minor layout tweaks
    [stevekey.kicad_pcb]
2023-10-11 Write Gerbers to gerbers/
    [stevekey.kicad_pcb]
2023-10-11 Add PDF schematic and Gerber files
2023-10-27 Pushing button sets LED and 4066 contact
2023-10-28 Add photo of board
2023-10-30 Fix detection when another key is held down
    [main.asm]
2023-10-30 Hold down Shift Lock to reset
    [main.asm]
2023-10-31 Separate reset into its own task
    [main.asm]
2023-11-01 Add routine to wait N milliseconds
2023-11-01 Fix double reset when Shift Lock is held down
    [main.asm]
2023-11-01 Run with 20 MHz internal oscillator
    [main.asm]
2023-11-04 Turn off LEDs during EEPROM write
2023-11-05 Use 330 ohm resistor for LEDs
    [stevekey.kicad_sch]
2023-11-05 Use internal pull-ups for keys
    [stevekey.kicad_pcb, stevekey.kicad_sch]
2023-11-05 Use "mxlock" for project files
    [mxlock.kicad_pcb, mxlock.kicad_sch]
2023-11-05 Add fourth key to the schematic
    [mxlock.kicad_sch]
2023-11-07 Add fourth key to the PCB layout
    [mxlock.kicad_pcb, mxlock.kicad_sch]
2023-11-07 Use consistent reference designators
    [mxlock.kicad_pcb, mxlock.kicad_sch]
2023-11-08 Add PDF schematic and gerbers for Rev 2
2023-11-09 Fix typo in signal name
    [main.asm]
2023-11-12 Outline reset circuit on schematic
    [mxlock.kicad_pcb, mxlock.kicad_sch]
2023-11-21 Drop down to 1 MHz to save a little power
2024-05-26 Ignore KiCad autosave files
2024-05-27 Upgrade to KiCad 8
    [mxlock.kicad_pcb, mxlock.kicad_sch]
2024-09-19 Sleep between keypresses to save power
2025-09-22 Update to KiCad 9 format
    [mxlock.kicad_pcb, mxlock.kicad_sch]
2025-11-16 Fix hang at power-on caused by ccdb1fbb6e46af6dde97c36fcbb627271af4deb3
2025-11-18 Add notes on power consumption and EEPROM life

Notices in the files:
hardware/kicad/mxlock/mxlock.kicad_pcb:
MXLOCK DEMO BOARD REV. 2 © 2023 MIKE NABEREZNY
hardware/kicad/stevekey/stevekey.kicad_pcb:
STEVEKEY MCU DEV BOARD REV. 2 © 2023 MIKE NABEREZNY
